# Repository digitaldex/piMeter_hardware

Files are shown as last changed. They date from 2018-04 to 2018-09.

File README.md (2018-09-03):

# piMeter - a SmartMeter for Raspberry Pi

Repo got cleaned up. You can find the new Software Version in my [piMeter_grafana](https://github.com/digitaldex/piMeter_grafana) Repo.

This one here is now only for the Hardware Part of this Project.

## Board
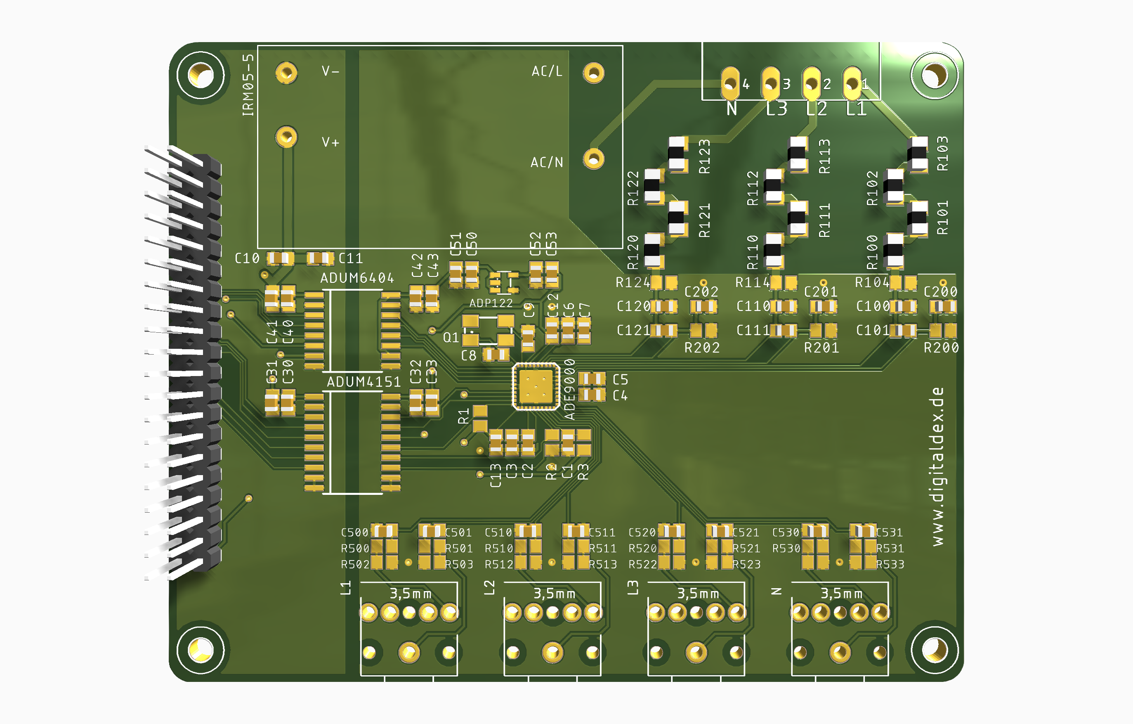
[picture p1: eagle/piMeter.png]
Eagle Board Screenshot


## Case
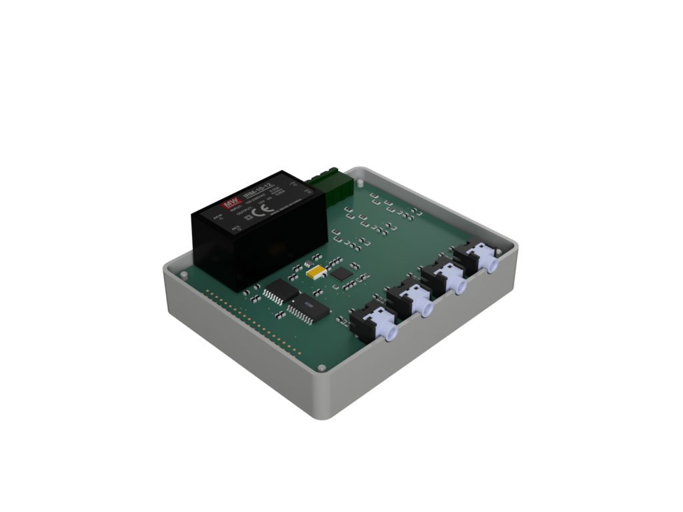
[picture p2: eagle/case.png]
piMeter Case Screenshot


## Schematics
[piMeter Schematics](https://github.com/digitaldex/piMeter_hardware/blob/master/eagle/Schematics.pdf)

## Ressources

[ADE9000 Datasheet](http://www.analog.com/media/en/technical-documentation/data-sheets/ADE9000.pdf)

[bcm2835 Library](http://www.airspayce.com/mikem/bcm2835/)

[InfluxDB Library](https://github.com/orca-zhang/influxdb-cpp)

[www.digitaldex.de](http://www.digitaldex.de)

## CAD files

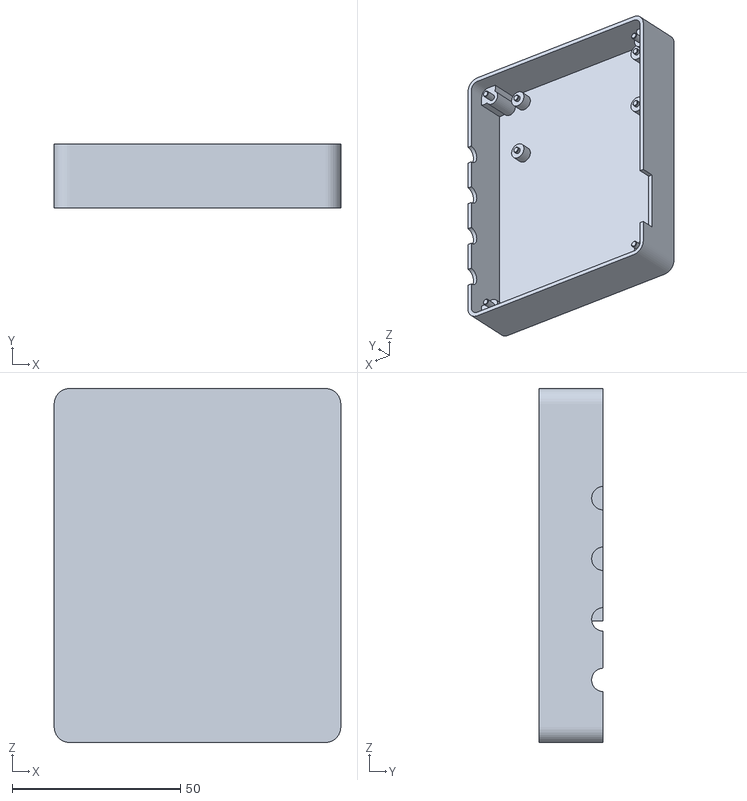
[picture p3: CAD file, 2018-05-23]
case/Bottom.stl
85.2 x 19.1 x 105.2

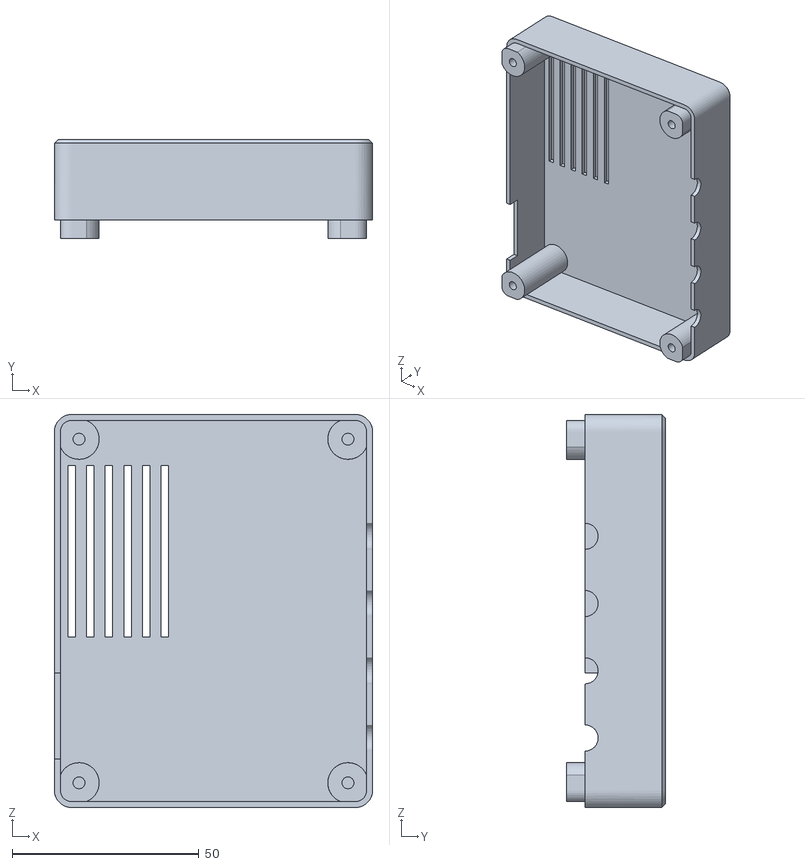
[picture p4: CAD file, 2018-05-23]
case/Top.stl
85.2 x 26.5 x 105.2

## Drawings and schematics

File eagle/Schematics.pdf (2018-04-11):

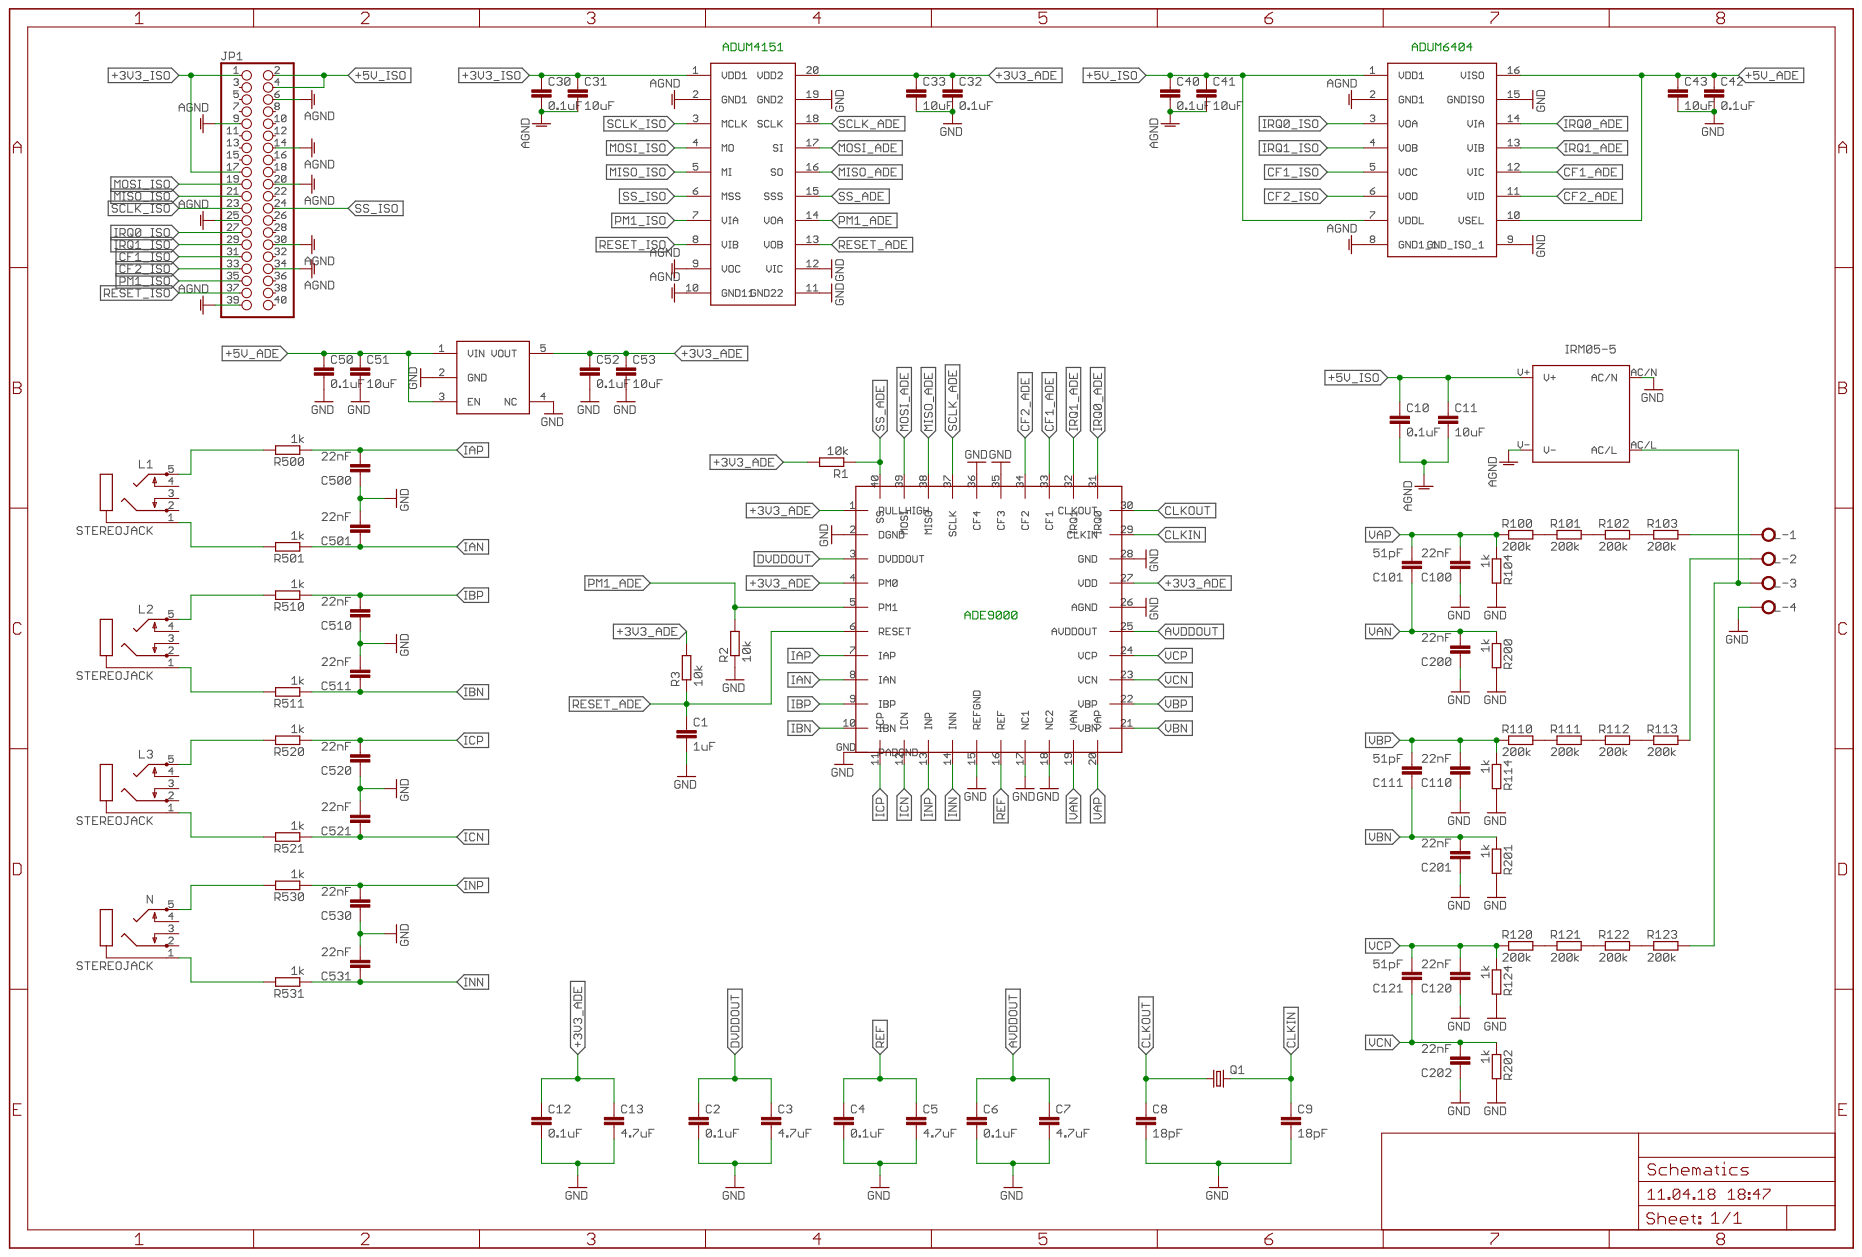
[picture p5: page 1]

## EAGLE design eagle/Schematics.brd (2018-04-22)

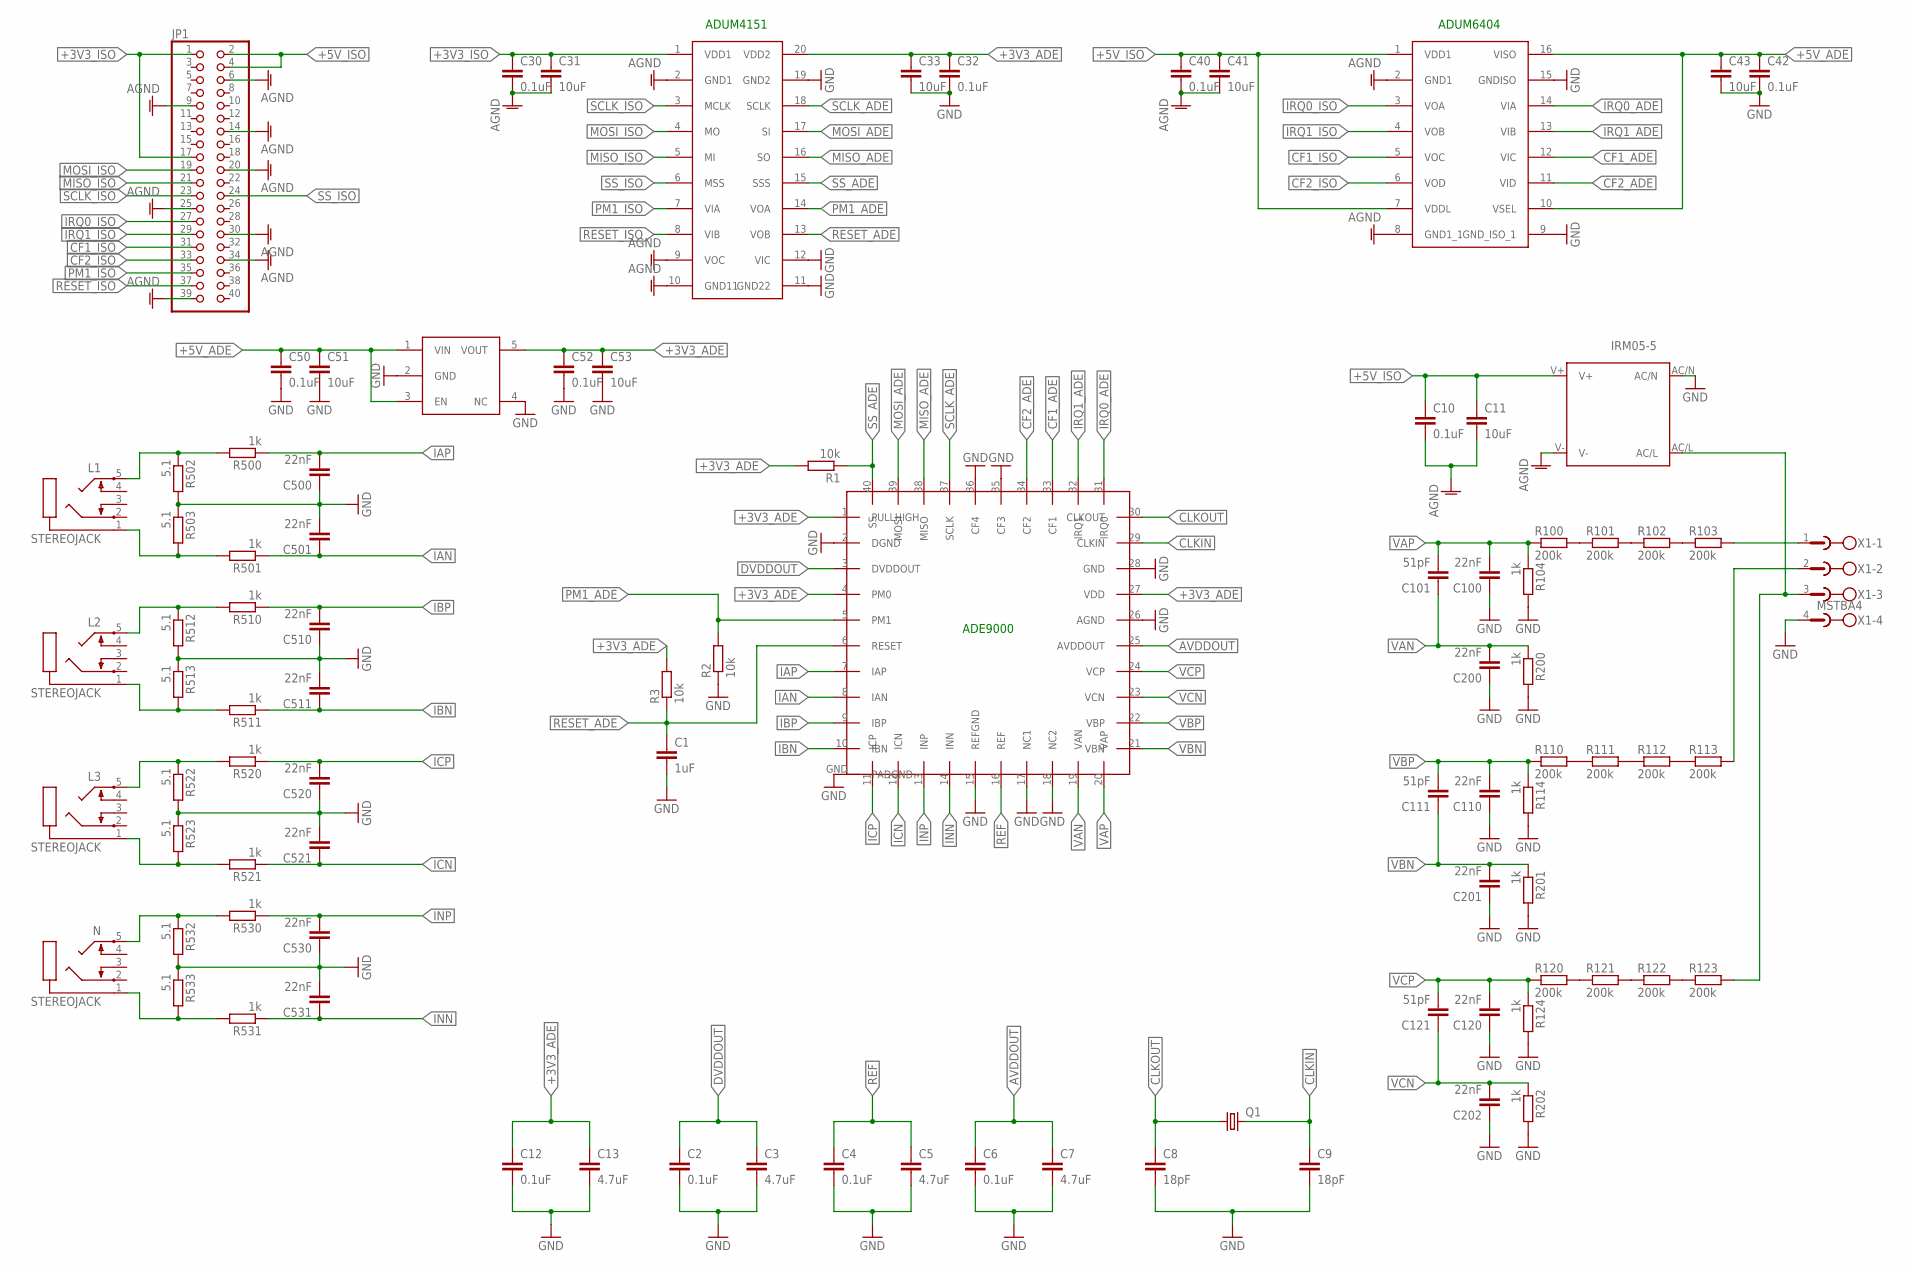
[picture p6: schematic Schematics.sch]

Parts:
ADE9000: ADE9000; LFCSP40
ADUM4151: ADUM4151; SOIC20R
ADUM6404: ADUM6404; SOIC16R
C1: 1uF; C0805
C2, C4, C6, C10, C12, C30, C32, C40, C42, C50, C52: 0.1uF; C0805
C3, C5, C7, C13: 4.7uF; C0805
C8, C9: 18pF; C0805
C11, C31, C33, C41, C43, C51, C53: 10uF; C0805
C100, C110, C120, C200, C201, C202, C500, C501, C510, C511, C520, C521, C530, C531: 22nF; C0805
C101, C111, C121: 51pF; C0805
IRM05-5: IRM_05/10
JP1: PINHD-2X20; 2X20
L1, L2, L3: STEREOJACK; STX3100
N: STEREOJACK; STX3100
Q1: CRYSTALCTS406; CTS406
R1, R2, R3: 10k; M0805
R100, R101, R102, R103, R110, R111, R112, R113, R120, R121, R122, R123: 200k; M1206
R104, R114, R124, R200, R201, R202, R500, R501, R510, R511, R520, R521, R530, R531: 1k; M0805
R502, R503, R512, R513, R522, R523, R532, R533: 5.1; M0805
U$5: ADP122AUJZ-3.3-R7; TSOT23-5L
X1: MSTBA4

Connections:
+3V3_ADE: ADE9000.1 (PULLHIGH), ADE9000.4 (PM0), ADE9000.27 (VDD), ADUM4151.20 (VDD2), C12.1, C13.1, C32.1, C33.1, C52.1, C53.1, R1.2, R3.2, U$5.5 (VOUT)
+3V3_ISO: ADUM4151.1 (VDD1), C30.1, C31.1, JP1.1, JP1.17
+5V_ADE: ADUM6404.10 (VSEL), ADUM6404.16 (VISO), C42.1, C43.1, C50.1, C51.1, U$5.1 (VIN), U$5.3 (EN)
+5V_ISO: ADUM6404.1 (VDD1), ADUM6404.7 (VDDL), C10.1, C11.1, C40.1, C41.1, IRM05-5.V+, JP1.2, JP1.4
AGND: ADUM4151.2 (GND1), ADUM4151.9 (VOC), ADUM4151.10 (GND11), ADUM6404.2 (GND1), ADUM6404.8 (GND1_1), C10.2, C11.2, C30.2, C31.2, C40.2, C41.2, IRM05-5.V-, JP1.6, JP1.9, JP1.14, JP1.20, JP1.25, JP1.30, JP1.34, JP1.39
AVDDOUT: ADE9000.25 (AVDDOUT), C6.1, C7.1
CF1_ADE: ADE9000.33 (CF1), ADUM6404.12 (VIC)
CF1_ISO: ADUM6404.5 (VOC), JP1.31
CF2_ADE: ADE9000.34 (CF2), ADUM6404.11 (VID)
CF2_ISO: ADUM6404.6 (VOD), JP1.33
CLKIN: ADE9000.29 (CLKIN), C9.1, Q1.3 (2)
CLKOUT: ADE9000.30 (CLKOUT), C8.1, Q1.1
DVDDOUT: ADE9000.3 (DVDDOUT), C2.1, C3.1
GND: ADE9000.2 (DGND), ADE9000.15 (REFGND), ADE9000.17 (NC1), ADE9000.18 (NC2), ADE9000.26 (AGND), ADE9000.28 (GND), ADE9000.35 (CF3), ADE9000.36 (CF4), ADE9000.GND, ADUM4151.11 (GND22), ADUM4151.12 (VIC), ADUM4151.19 (GND2), ADUM6404.9 (GND_ISO_1), ADUM6404.15 (GNDISO), C1.2, C2.2, C3.2, C4.2, C5.2, C6.2, C7.2, C8.2, C9.2, C12.2, C13.2, C32.2, C33.2, C42.2, C43.2, C50.2, C51.2, C52.2, C53.2, C100.1, C110.1, C120.1, C200.1, C201.1, C202.1, C500.1, C501.2, C510.1, C511.2, C520.1, C521.2, C530.1, C531.2, IRM05-5.AC/N, R2.1, R104.2, R114.2, R124.2, R200.2, R201.2, R202.2, R502.2, R503.1, R512.2, R513.1, R522.2, R523.1, R532.2, R533.1, U$5.2 (GND), U$5.4 (NC), X1.4
IAN: ADE9000.8 (IAN), C501.1, R501.1
IAP: ADE9000.7 (IAP), C500.2, R500.1
IBN: ADE9000.10 (IBN), C511.1, R511.1
IBP: ADE9000.9 (IBP), C510.2, R510.1
ICN: ADE9000.12 (ICN), C521.1, R521.1
ICP: ADE9000.11 (ICP), C520.2, R520.1
INN: ADE9000.14 (INN), C531.1, R531.1
INP: ADE9000.13 (INP), C530.2, R530.1
IRQ0_ADE: ADE9000.31 (IRQ0), ADUM6404.14 (VIA)
IRQ0_ISO: ADUM6404.3 (VOA), JP1.27
IRQ1_ADE: ADE9000.32 (IRQ1), ADUM6404.13 (VIB)
IRQ1_ISO: ADUM6404.4 (VOB), JP1.29
MISO_ADE: ADE9000.38 (MISO), ADUM4151.16 (SO)
MISO_ISO: ADUM4151.5 (MI), JP1.21
MOSI_ADE: ADE9000.39 (MOSI), ADUM4151.17 (SI)
MOSI_ISO: ADUM4151.4 (MO), JP1.19
unnamed: R121.2, R122.1
unnamed: R102.2, R103.1
unnamed: R103.2, X1.1
unnamed: L1.5, R500.2, R502.1
unnamed: L1.1, R501.2, R503.2
unnamed: L2.5, R510.2, R512.1
unnamed: L2.1, R511.2, R513.2
unnamed: L3.5, R520.2, R522.1
unnamed: L3.1, R521.2, R523.2
unnamed: N.5, R530.2, R532.1
unnamed: N.1, R531.2, R533.2
unnamed: R101.2, R102.1
unnamed: R111.2, R112.1
unnamed: R112.2, R113.1
unnamed: R122.2, R123.1
unnamed: R113.2, X1.2
unnamed: IRM05-5.AC/L, R123.2, X1.3
unnamed: R110.2, R111.1
unnamed: R100.2, R101.1
unnamed: R120.2, R121.1
PM1_ADE: ADE9000.5 (PM1), ADUM4151.14 (VOA), R2.2
PM1_ISO: ADUM4151.7 (VIA), JP1.35
REF: ADE9000.16 (REF), C4.1, C5.1
RESET_ADE: ADE9000.6 (RESET), ADUM4151.13 (VOB), C1.1, R3.1
RESET_ISO: ADUM4151.8 (VIB), JP1.37
SCLK_ADE: ADE9000.37 (SCLK), ADUM4151.18 (SCLK)
SCLK_ISO: ADUM4151.3 (MCLK), JP1.23
SS_ADE: ADE9000.40 (SS), ADUM4151.15 (SSS), R1.1
SS_ISO: ADUM4151.6 (MSS), JP1.24
VAN: ADE9000.19 (VAN), C101.1, C200.2, R200.1
VAP: ADE9000.20 (VAP), C100.2, C101.2, R100.1, R104.1
VBN: ADE9000.21 (VBN), C111.1, C201.2, R201.1
VBP: ADE9000.22 (VBP), C110.2, C111.2, R110.1, R114.1
VCN: ADE9000.23 (VCN), C121.1, C202.2, R202.1
VCP: ADE9000.24 (VCP), C120.2, C121.2, R120.1, R124.1

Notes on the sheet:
ADUM4151
ADE9000
ADUM6404

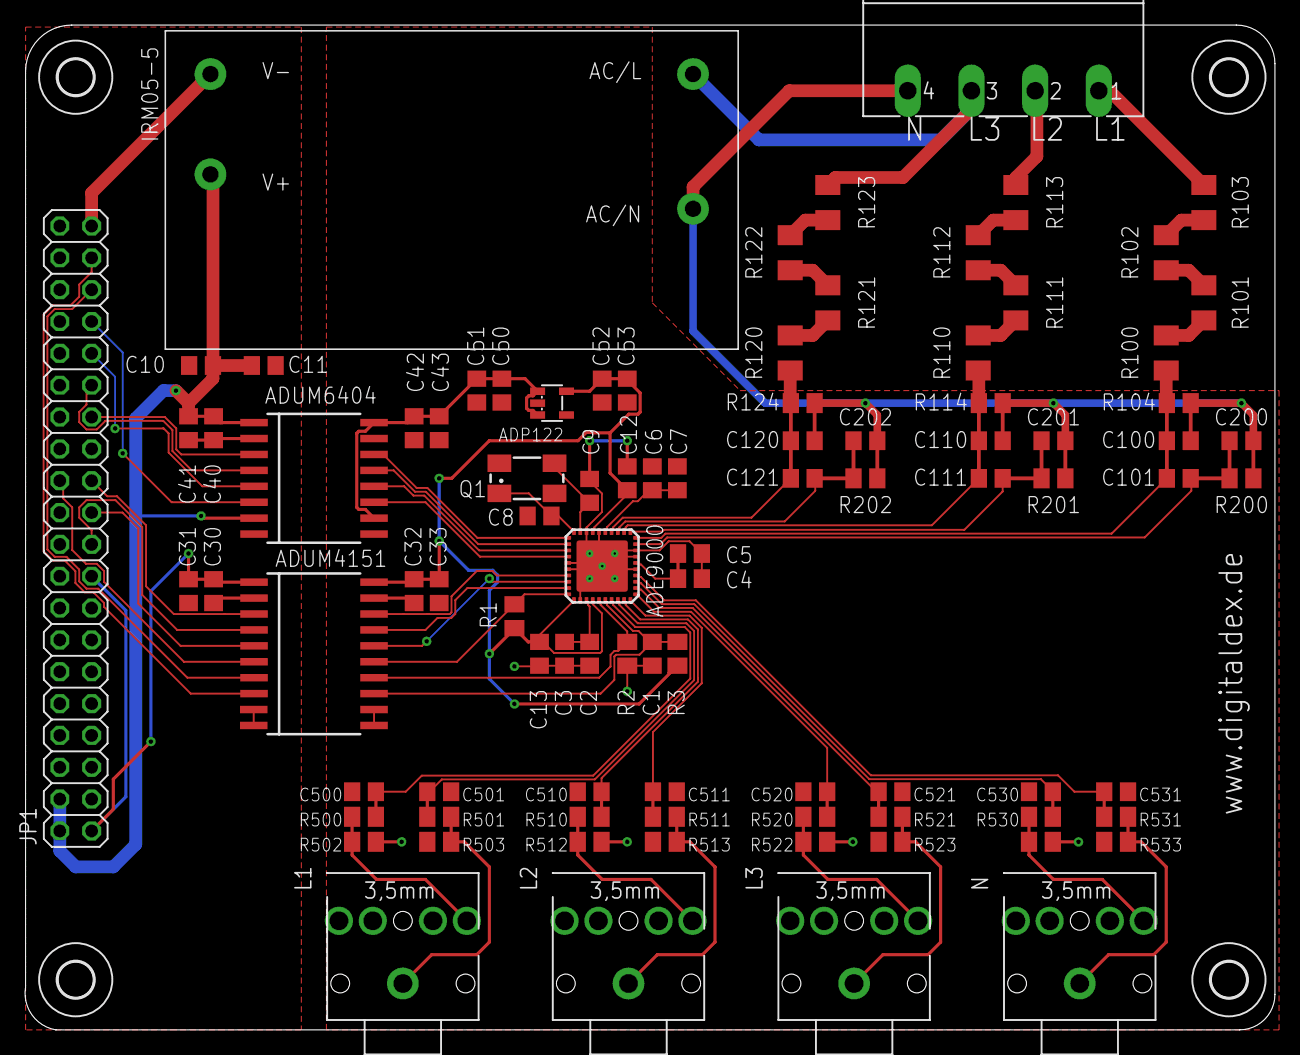
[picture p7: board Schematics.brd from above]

Board: 2 copper layers, 99.7 x 80.2 mm, 95 parts (0 on the bottom side), 65 nets.

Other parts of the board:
U$1, U$2, U$3, U$4: 2,8

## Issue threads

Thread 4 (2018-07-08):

Is the ADUM6404 VDDL pin ..wrong voltage

koenver, 2018-07-08:
I think the PCB has a wrong connection at the ADUM6404 VDDL pin.
Now it is connected to the +5V_ISO..so the output of the ADUM6404 VOA..VOD is between 0 and 5 V, that's bad for the raspberry.
When I connect the VDDL pin of the ADUM6404 at +3V3_ISO the logic levels are normal between 0 and 3.3V.  ...I tested this and this was correct.

greetings
Koen

digitaldex, 2018-07-08:
You are right. The ADUM Data Channels in this configuration work with 5V. I was thinking the gpio pins on the pi are 5V tolerant but in fact they are not.

But for your workaround check the ADUM Datasheet:

> Page 16 Table 25 Data Channel Supply Voltage, 3.0 V to 5.5 V. Pin 1 and Pin 7 must be connected to the same external voltage source.

This is not the case if you use 3.3V on the VDDL Pin. To be safe use a Voltage Divider for CF1, CF2, IRQ1 and IRQ2 if you realy need those pins. i havent used any of these right now.

koenver, 2018-07-08:
Sorry, but I think AD devices means with the same voltage source..the same voltage group... at the same side of the chip.  According to the datasheet VDD1 (5V) with GND1 and with the 3V3 must also have GND1 as ground.
It works perfect..I lifted the VDDL pin and soldered a wire to it to 3V3 (from raspberry side)...Than I tested with 3V3_ADE (high and low at the input pins) and at the output pins was a nice 3V3_raspberry or zero (GND1)..
Its a bit confusing because the AD spreadsheet calls the left side" ISO" and  digitaldex the right side of the chip "ISO"

koenver, 2018-07-08:
No I am using your basic design and mixed with the original evaluation board...so not the current headphone connectors, also the rogowski components are back,  Aswell a raspberry as a ESP32 (D4 micro) can be connected and a GPS (tx,rx,pps).
With jumpers it's selectable between CF1/CF3 and CF2/CF4  (CF1 and CF2 are only needed for calibration), while CF4 gives the zero crossing...
But I also forgot in case of the ESP32 that normally the Raspberry generates the 3V3 from the 5V :)..
but it a litte micro pcb in the RP slot created the 3V3 also :)....and  I had the ADUM6404 VDDL mistake..
If every thing is succesfull and I fix these errors I will publish the PCB and Eagle files.

koen

digitaldex, 2018-07-09:
Okay thanks for the info. I will fix this soon and close the issue when i am done

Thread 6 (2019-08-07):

Boards or HW

mgiaco, 2019-08-07:
Hi,

Do you sell a pcb or a finished hardware anywhere?

best regards,
mathias

digitaldex, 2019-08-07:
Hello,

no there is no shop or anything like that.

Closed 2021-08-01.
